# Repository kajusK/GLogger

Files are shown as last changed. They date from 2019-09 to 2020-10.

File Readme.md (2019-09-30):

GLogger
==========

GLogger is minimalistic GPS logger designed with low power consumption in mind.

I was missing a device that would be able to log my hiking and motorbike trips
that were several days long. Using smartphone is no-go for high battery
consumption. Sport watches can work just for two or three days.
Consumer grade GPS loggers sold today are usually designed for sending GPS
location to some cloud.

Features
--------
 * Low battery consumption, can log one location per minute for several weeks,
    designed for more than 40 days of continuous operation
   (turn on at first day of your trip and forget)
 * Measuring distance travelled since power-on and since
   last clear request
 * Powered by CR123 battery or rechargeable equivalent (integrated charger)
 * Lightweight (only TODO grams with battery included)
 * Downloading data from device over USB in GPX format (easy to import to most
   of the sport trackers, etc.), no special PC side software needed

Hardware
========
 * Based on cheap STM32F0 ARM MCU
 * Cheap GPS module SIM28ML, can be replaced with U-Blox (almost pin compatible)
 * External SPI flash for GPS log storage (much lower power consumption than SD
   card)
 * Micro USB for communication with PC
 * OLED display and 2 buttons for user interaction

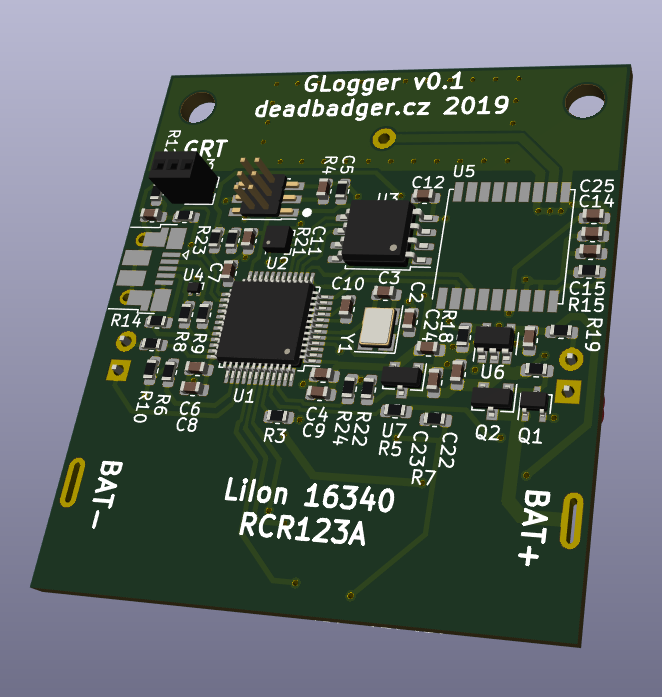
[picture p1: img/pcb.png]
pcb


Software
========
 * Running on top of the [libopencm3](http://libopencm3.org/)
 * Tiny custom graphical library written just for fun
 * Used script from [ChibiOS-Contrib](https://github.com/ChibiOS/ChibiOS-Contrib/blob/master/tools/mx2board.py)
   to generate GPIO configuration from STM32CubeMx without HAL overhead
 * Real time conversion from GPS logs stored in flash to emulated FatFs GPX file

Folders
=======
 * _fw/projects_ - TrueStudio projects for firmware itself, bootloader,...
 * _fw/sources_ - All FW source files
 * _fw/sources/app_ - project specific sources
 * _hw_ - Hardware design files - PCB, enclosure,...
 * _tools_ - various helper scripts
 * _tools/cgui_ - image and font generators for custom GUI

Licensing
=========
The project files can be used under terms in [License_SW](License_SW) and
[License_HW](License_HW).

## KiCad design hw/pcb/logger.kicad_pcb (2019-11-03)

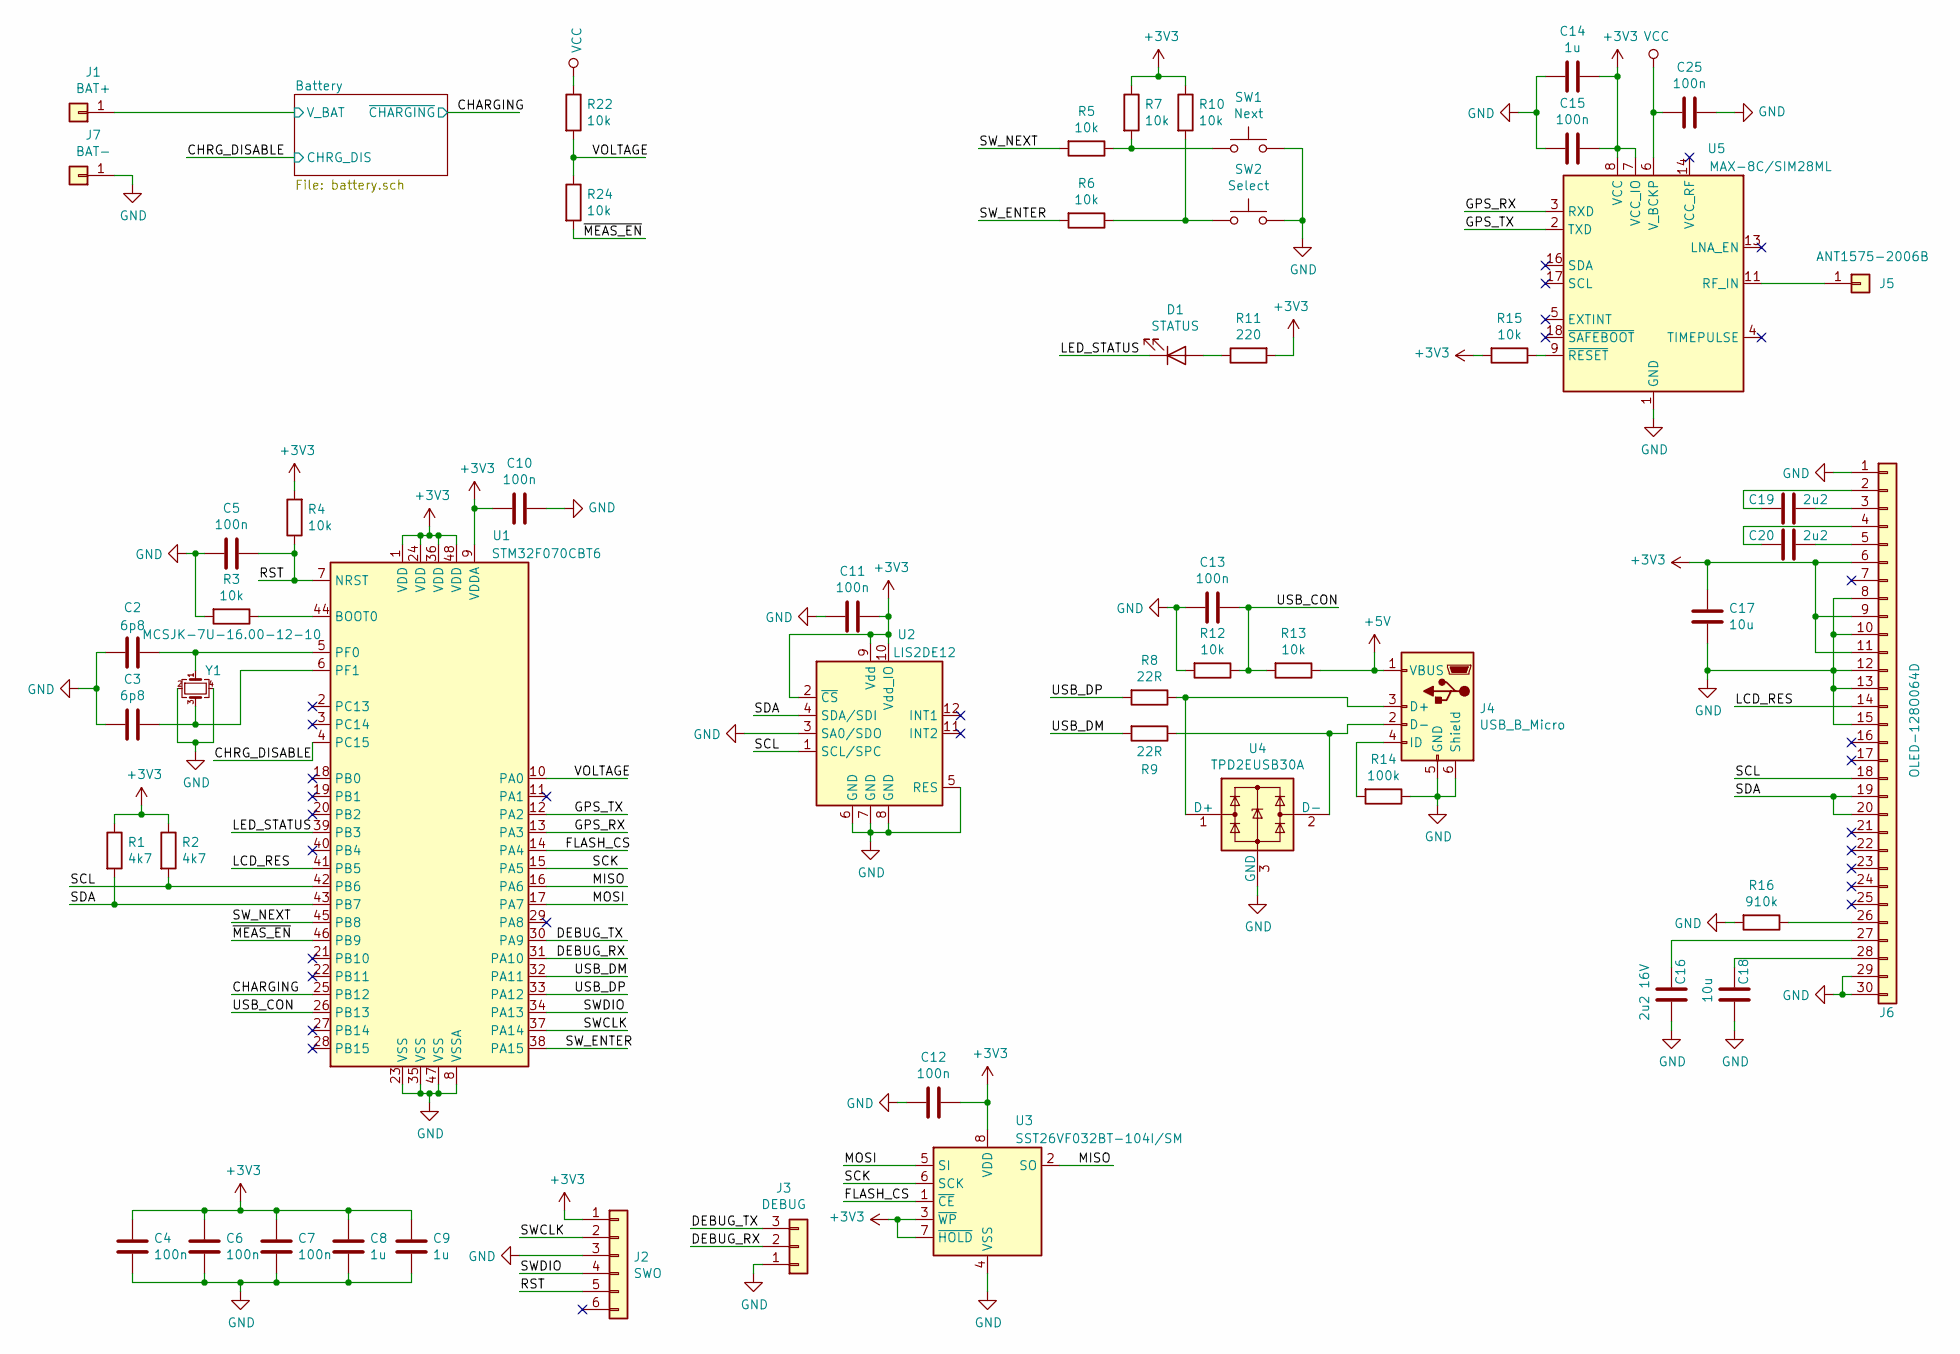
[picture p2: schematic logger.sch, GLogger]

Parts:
C2, C3: 6p8; C_0603_1608Metric
C4, C5, C6, C7, C10, C11, C12, C13, C15, C25: 100n; C_0603_1608Metric
C8, C9, C14: 1u; C_0603_1608Metric
C16: 2u2 16V; C_0603_1608Metric
C17, C18: 10u; C_0603_1608Metric
C19, C20: 2u2; C_0603_1608Metric
D1: STATUS; LED_D3.0mm
J1: BAT+; SolderWirePad_1x01_Drill0.8mm
J2: SWO; PinHeader_2x03_P1.27mm_Vertical_SMD
J3: DEBUG; PinSocket_1x03_P1.27mm_Vertical
J4: USB_B_Micro; USB_Micro-B_Amphenol_10103594-0001LF_Horizontal
J5: ANT1575-2006B; SolderWirePad_1x01_Drill1.2mm
J6: OLED-128O064D
J7: BAT-; SolderWirePad_1x01_Drill0.8mm
R1, R2: 4k7; R_0603_1608Metric
R3, R4, R5, R6, R7, R10, R12, R13, R15, R22, R24: 10k; R_0603_1608Metric
R8, R9: 22R; R_0603_1608Metric
R11: 220; R_0603_1608Metric
R14: 100k; R_0603_1608Metric
R16: 910k; R_0603_1608Metric
SW1: Next; SW_SPST_PTS645
SW2: Select; SW_SPST_PTS645
U1: STM32F070CBT6; LQFP-48_7x7mm_P0.5mm
U2: LIS2DE12; LGA-12_2x2mm_P0.5mm
U3: SST26VF032BT-104I/SM; SOIC-8_5.275x5.275mm_P1.27mm
U4: TPD2EUSB30A; Texas_DRT-3
U5: MAX-8C/SIM28ML; ublox_MAX
Y1: MCSJK-7U-16.00-12-10; Crystal_SMD_3225-4Pin_3.2x2.5mm

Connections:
+3V3: C4.1, C6.1, C7.1, C8.1, C9.1, C10.1, C11.1, C12.1, C14.1, C15.1, C17.1, J2.1, J6.6, J6.9, J6.11, R1.1, R2.1, R4.2, R7.1, R10.1, R11.2, R15.2, U1.1 (VDD), U1.9 (VDDA), U1.24 (VDD), U1.36 (VDD), U1.48 (VDD), U2.2 (~CS), U2.9 (Vdd), U2.10 (Vdd_IO), U3.3 (~WP~), U3.7 (~HOLD~), U3.8 (VDD), U5.7 (VCC_IO), U5.8 (VCC); also elsewhere on the board
+5V: J4.1 (VBUS), R13.1; also elsewhere on the board
/Battery/V_BAT: J1.1; also elsewhere on the board
/CHARGING: U1.25 (PB12); also elsewhere on the board
/CHRG_DISABLE: U1.4 (PC15); also elsewhere on the board
/DEBUG_RX: J3.2, U1.31 (PA10)
/DEBUG_TX: J3.3, U1.30 (PA9)
/FLASH_CS: U1.14 (PA4), U3.1 (~CE)
/GPS_RX: U1.13 (PA3), U5.3 (RXD)
/GPS_TX: U1.12 (PA2), U5.2 (TXD)
/LCD_RES: J6.14, U1.41 (PB5)
/LED_STATUS: D1.1 (K), U1.39 (PB3)
/MISO: U1.16 (PA6), U3.2 (SO)
/MOSI: U1.17 (PA7), U3.5 (SI)
/RST: C5.1, J2.5, R4.1, U1.7 (NRST)
/SCK: U1.15 (PA5), U3.6 (SCK)
/SCL: J6.18, R2.2, U1.42 (PB6), U2.1 (SCL/SPC)
/SDA: J6.19, J6.20, R1.2, U1.43 (PB7), U2.4 (SDA/SDI)
/SWCLK: J2.2, U1.37 (PA14)
/SWDIO: J2.4, U1.34 (PA13)
/SW_ENTER: R6.2, U1.38 (PA15)
/SW_NEXT: R5.2, U1.45 (PB8)
/USB_CON: C13.1, R12.1, R13.2, U1.26 (PB13)
/USB_DM: R9.2, U1.32 (PA11)
/USB_DP: R8.2, U1.33 (PA12)
/VOLTAGE: R22.2, R24.1, U1.10 (PA0)
/~MEAS_EN: R24.2, U1.46 (PB9)
GND: C2.2, C3.2, C4.2, C5.2, C6.2, C7.2, C8.2, C9.2, C10.2, C11.2, C12.2, C13.2, C14.2, C15.2, C16.2, C17.2, C18.2, C25.1, J2.3, J3.1, J4.5 (GND), J4.6 (Shield), J6.1, J6.8, J6.10, J6.12, J6.13, J6.15, J6.29, J6.30, J7.1, R3.2, R12.2, R14.1, R16.2, SW1.2, SW2.2, U1.8 (VSSA), U1.23 (VSS), U1.35 (VSS), U1.47 (VSS), U2.3 (SA0/SDO), U2.5 (RES), U2.6 (GND), U2.7 (GND), U2.8 (GND), U3.4 (VSS), U4.3 (GND), U5.1 (GND), U5.10 (GND), U5.12 (GND), Y1.2, Y1.4; also elsewhere on the board
unnamed: C2.1, U1.5 (PF0), Y1.1
unnamed: C3.1, U1.6 (PF1), Y1.3
unnamed: C16.1, J6.27
unnamed: C18.1, J6.28
unnamed: C19.1, J6.3
unnamed: C19.2, J6.2
unnamed: C20.1, J6.5
unnamed: C20.2, J6.4
unnamed: D1.2 (A), R11.1
unnamed: J4.2 (D-), R9.1, U4.2 (D-)
unnamed: J4.3 (D+), R8.1, U4.1 (D+)
unnamed: J4.4 (ID), R14.2
unnamed: J5.1, U5.11 (RF_IN)
unnamed: J6.26, R16.1
unnamed: R3.1, U1.44 (BOOT0)
unnamed: R5.1, R7.2, SW1.1
unnamed: R6.1, R10.2, SW2.1
unnamed: R15.1, U5.9 (~RESET)
VCC: C25.2, R22.1, U5.6 (V_BCKP); also elsewhere on the board

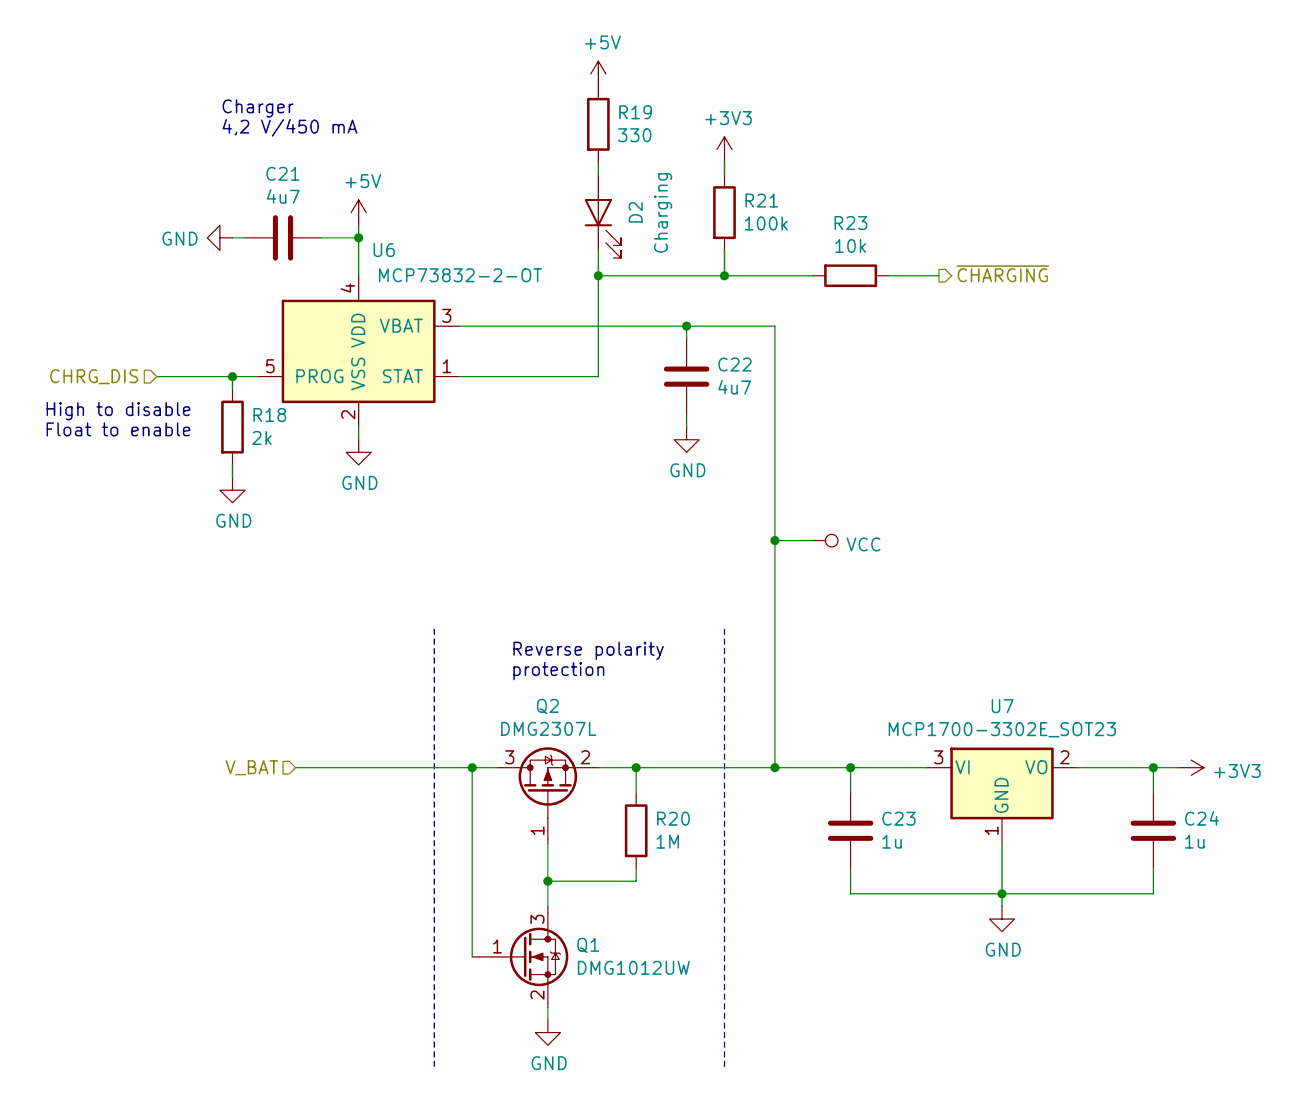
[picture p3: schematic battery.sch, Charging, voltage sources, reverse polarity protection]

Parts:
C21, C22: 4u7; C_0603_1608Metric
C23, C24: 1u; C_0603_1608Metric
D2: Charging; LED_D3.0mm
Q1: DMG1012UW; SOT-323_SC-70
Q2: DMG2307L; SOT-23
R18: 2k; R_0603_1608Metric
R19: 330; R_0603_1608Metric
R20: 1M; R_0603_1608Metric
R21: 100k; R_0603_1608Metric
R23: 10k; R_0603_1608Metric
U6: MCP73832-2-OT; SOT-23-5
U7: MCP1700-3302E_SOT23; SOT-23

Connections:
+3V3: C24.1, R21.1, U7.2 (VO); also elsewhere on the board
+5V: C21.1, R19.1, U6.4 (VDD); also elsewhere on the board
/Battery/V_BAT: Q1.1 (G), Q2.3 (D); also elsewhere on the board
/CHARGING: R23.1; also elsewhere on the board
/CHRG_DISABLE: R18.1, U6.5 (PROG); also elsewhere on the board
GND: C21.2, C22.2, C23.2, C24.2, Q1.2 (S), R18.2, U6.2 (VSS), U7.1 (GND); also elsewhere on the board
unnamed: D2.1 (K), R21.2, R23.2, U6.1 (STAT)
unnamed: D2.2 (A), R19.2
unnamed: Q1.3 (D), Q2.1 (G), R20.2
VCC: C22.1, C23.1, Q2.2 (S), R20.1, U6.3 (VBAT), U7.3 (VI); also elsewhere on the board

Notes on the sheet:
High to disable Float to enable
Reverse polarity protection
Charger 4,2 V/450 mA

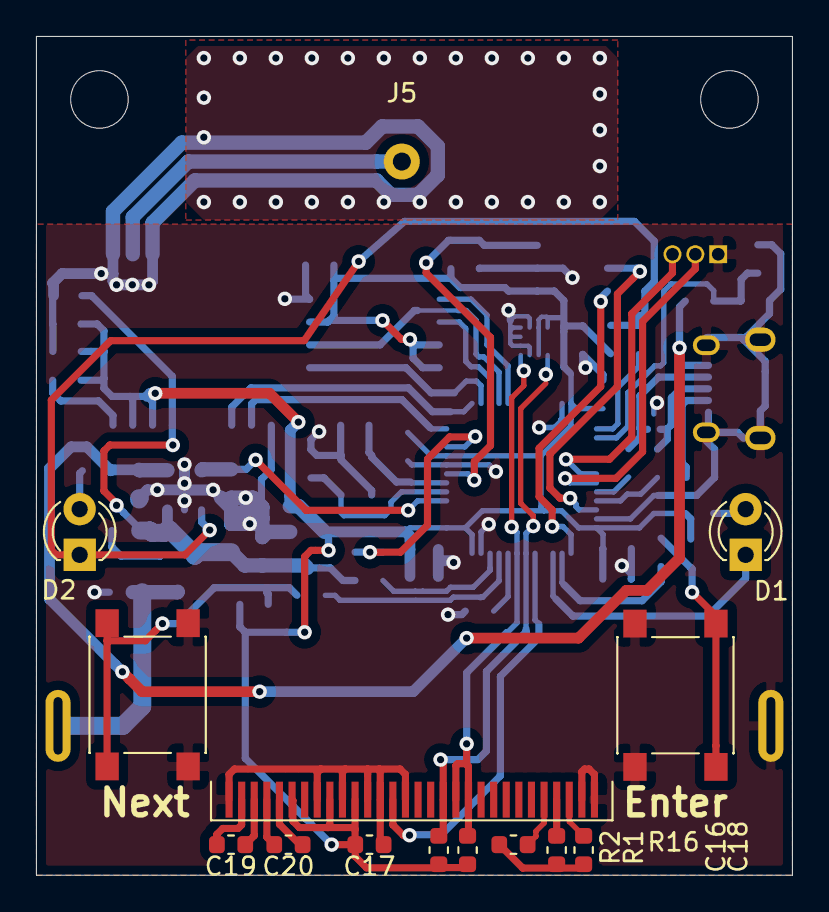
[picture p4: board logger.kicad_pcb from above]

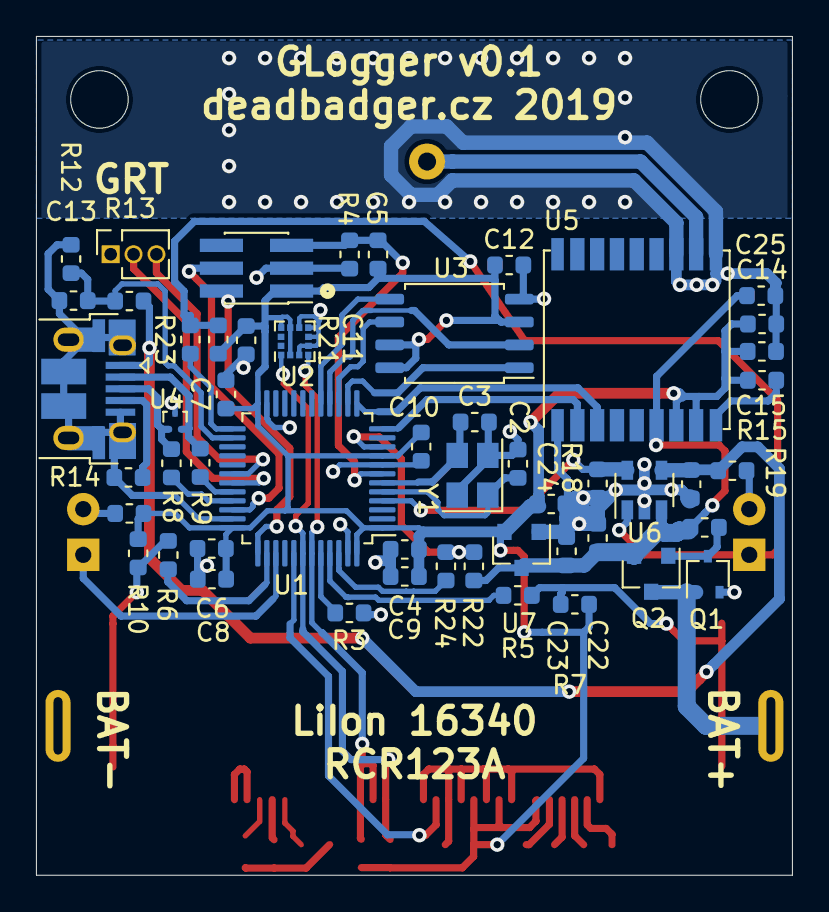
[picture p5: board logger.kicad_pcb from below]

Board: 2 copper layers, 42.0 x 46.6 mm, 68 parts (52 on the bottom side), 50 nets.

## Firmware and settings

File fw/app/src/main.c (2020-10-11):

/*
 * Copyright (C) 2019 Jakub Kaderka
 *
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
 * You should have received a copy of the GNU General Public License
 * along with this program.  If not, see <https://www.gnu.org/licenses/>.
 */

/**
 * @file    app/logger/main.c
 * @brief   Main file for GLogger app
 *
 * @addtogroup utils
 * @{
 */
#include <libopencm3/stm32/rcc.h>

#include <hal/io.h>
#include <hal/i2c.h>
#include <hal/spi.h>
#include <hal/uart.h>
#include <hal/wdg.h>
#include <hal/rtc.h>
#include <modules/log.h>
#include <modules/uf2.h>
#include <drivers/spi_flash.h>
#include <drivers/ssd1306.h>
#include <drivers/gps.h>
#include <utils/time.h>
#include <utils/button.h>
#include <modules/ramdisk.h>
#include "storage.h"
#include "stats.h"
#include "usb.h"
#include "gui/gui.h"
#include "gui/gui.h"
#include "utils/assert.h"
#include "version.h"

gps_desc_t gps_desc;
spiflash_desc_t spiflash_desc;
ssd1306_desc_t ssd1306_desc;

/**
 * Configure system clock
 *
 * External 16 MHz used to generate precise 48 MHz for USB
 * System clock running directly from crystal (16 MHz)
 */
static void setClock(void)
{
    /* Enable crystal oscillator and use it as a system clock */
    rcc_osc_on(RCC_HSE);
    rcc_wait_for_osc_ready(RCC_HSE);
    rcc_set_sysclk_source(RCC_HSE);

    rcc_apb1_frequency = 16000000;
    rcc_ahb_frequency = 16000000;

    /* No prescalers for system clock and peripherals */
    rcc_set_hpre(RCC_CFGR_HPRE_NODIV);
    rcc_set_ppre(RCC_CFGR_PPRE_NODIV);

    /* Setup PLL to generate 48 MHz for usb */
    rcc_set_pll_multiplication_factor(RCC_CFGR_PLLMUL_MUL6);
    rcc_set_pll_source(RCC_CFGR_PLLSRC_HSE_CLK);
    rcc_set_prediv(RCC_CFGR2_PREDIV_DIV2);
    rcc_osc_on(RCC_PLL);
    rcc_wait_for_osc_ready(RCC_PLL);
    rcc_set_usbclk_source(RCC_PLL);
}

static void addReadme(void)
{
    const char *readme = "GLogger gps logger by deadbadger.cz, for more info "
            "check out deadbadger.cz/projects/glogger.";

    Ramdisk_AddTextFile("README", "TXT", 0, readme);
}

static void btnCheck(void)
{
    static button_t bt_next = { LINE_SW_NEXT, };
    static button_t bt_enter = { LINE_SW_ENTER, };
    button_event_t event;

    event = Button(&bt_next);
    if (event == BTN_RELEASED_SHORT) {
        Gui_Event(GUI_EVT_SHORT_NEXT);
    } else if (event == BTN_LONG_PRESS) {
        Gui_Event(GUI_EVT_LONG_NEXT);
    }

    event = Button(&bt_enter);
    if (event == BTN_RELEASED_SHORT) {
        Gui_Event(GUI_EVT_SHORT_ENTER);
    } else if (event == BTN_LONG_PRESS) {
        //TODO poweroff
    }
}

static void loop(void)
{
    uint32_t time = millis();
    const gps_info_t *gps;

    // turn on the gps
    // while gps not valid
        // sleep until woken up by interrupt, process nema, if not complete, sleep
    //store gps position
    //turn off the gps
    //go to stop mode, wait for rtc to wake mcu up

    //wake up sources - buttons in on mode, holding button in off mode

    //read buttons, if pressed, turn on display, set turn off timer

    gps = Gps_Loop(&gps_desc);
    if (gps != NULL) {
        //TODO verify target has moved since last gps fix
        Stats_Update(gps);
        Storage_Add(gps);
        Gui_Event(GUI_EVT_REDRAW);
    }

    if (time % 5 == 0) {
        btnCheck();
    }
}

static void fw_read(uint32_t offset, uint8_t *buf, size_t len)
{
    (void)len;
    UF2_Read(buf, offset/512);
}

static void ramdisk_write(const uint8_t *buf, size_t size, uint32_t offset)
{
    (void)size;
    (void)offset;
    UF2_Write(buf);
}

int main(void)
{
    static uint8_t fbuf[SSD1306_FBUF_SIZE];
    /* Initialize clock system, IO pins and systick */
    setClock();
    IOd_Init();
    Time_Init();

    /* early init - debug output */
    UARTd_Init(USART_DEBUG_TX, 115200);
    Log_Init(USART_DEBUG_TX);
    Log_SetLevel(LOG_DEBUG);
    Log_Info(NULL, "GLogger, fw version %d.%d", FW_MAJOR, FW_MINOR);
    Log_Info(NULL, "Deadbadger.cz");

    I2Cd_Init(1, true);
    SPId_Init(1, SPID_PRESC_2, SPI_MODE_0);
    UARTd_Init(USART_GPS_TX, 9600);
    RTCd_Init(false);

    if (SSD1306_Init(&ssd1306_desc, fbuf, 1,
            SSD1306_ADDR_0, LINE_SSD1306_RES) == false) {
        Log_Error("I2C", "Failed to initialize display driver");
    } else {
        SSD1306_SetOrientation(&ssd1306_desc, true);
        SSD1306_DispEnable(&ssd1306_desc, true);
    }
    Gui_Init();

    Gps_Init(&gps_desc, USART_GPS_RX);
    SpiFlash_Init(&spiflash_desc, 1, LINE_FLASH_CS);
    SpiFlash_WriteUnlock(&spiflash_desc);
    Storage_Init();
    //Stats_Init();

    Ramdisk_Init(64000000, "GLogger");
    Ramdisk_RegisterWriteCb(ramdisk_write);
    addReadme();
    Ramdisk_AddFile("fw", "uf2", 0, UF2_GetImgSize(), fw_read);
    Usb_Init();

    Gui_Event(GUI_EVT_REDRAW);
    Log_Info(NULL, "System initialized, running main loop");
    while (1) {
        loop();
        Usb_Poll();
    }
}

/** @} */

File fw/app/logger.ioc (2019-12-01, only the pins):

Mcu.UserName=STM32F070CBTx
PA0.GPIO_Label=VOLTAGE
PA0.Signal=ADC_IN0
PA10.GPIO_Label=DEBUG_RX
PA10.Signal=USART1_RX
PA11.Signal=USB_DM
PA12.Signal=USB_DP
PA13.Signal=SYS_SWDIO
PA14.Signal=SYS_SWCLK
PA15.GPIO_Label=SW_ENTER
PA15.Signal=GPIO_Input
PA2.GPIO_Label=GPS_TX
PA2.Signal=USART2_TX
PA3.GPIO_Label=GPS_RX
PA3.Signal=USART2_RX
PA4.GPIO_Label=FLASH_CS
PA4.Signal=GPIO_Output
PA5.Signal=SPI1_SCK
PA6.Signal=SPI1_MISO
PA7.Signal=SPI1_MOSI
PA9.GPIO_Label=DEBUG_TX
PA9.Signal=USART1_TX
PB12.GPIO_Label=CHARGING
PB12.Signal=GPIO_Input
PB13.GPIO_Label=USB_CON
PB13.Signal=GPIO_Input
PB3.GPIO_Label=LED_STATUS
PB3.Signal=GPIO_Output
PB5.GPIO_Label=SSD1306_RES
PB5.Signal=GPIO_Output
PB6.Signal=I2C1_SCL
PB7.Signal=I2C1_SDA
PB8.GPIO_Label=SW_NEXT
PB8.Signal=GPIO_Input
PB9.GPIO_Label=MEAS_EN
PB9.Signal=GPIO_Input
PF0-OSC_IN.Signal=RCC_OSC_IN
PF1-OSC_OUT.Signal=RCC_OSC_OUT

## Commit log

2019-07-01 Added driver for spi flash
2019-07-02 Added mass storage USB driver
2019-07-02 Added puts function to uart
2019-07-03 Added GPS driver
2019-07-07 Fixed usb driver, changed ids and string from hardcoded to defines
2019-07-24 Improved cgui - printf, font metrics,...
2019-09-25 HW revision 0.1
    [battery.sch, logger.kicad_pcb, logger.sch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]
2019-11-03 Fixed getting spi device
2019-11-03 Added value to crystal caps
    [logger.kicad_pcb, logger.sch]
2019-11-20 Fixed i2c
2019-12-01 Fixed spi flash access
    [logger.ioc]
2019-12-01 Fixed i2c clock for fast mode, wait for transmission end before returning after nack
2019-12-09 Fixed ssd1306 driver
2019-12-12 Added putc to uart
2019-12-14 Added timeouts to i2c to avoid infinite loop
2019-12-14 Fixed macros in log, set logging uart
2019-12-15 Added button presses processing
2019-12-15 Check array bounds when writing to frame buffer
2020-10-09 Ported to new format of AFW drivers
2020-10-09 Set Log uart device by function call

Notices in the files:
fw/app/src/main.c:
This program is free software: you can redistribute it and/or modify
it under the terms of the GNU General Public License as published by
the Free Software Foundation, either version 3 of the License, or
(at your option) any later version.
